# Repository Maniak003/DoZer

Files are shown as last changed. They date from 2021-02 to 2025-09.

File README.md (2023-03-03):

<!DOCTYPE html>
<html lang="en" data-color-mode="auto" data-light-theme="light" data-dark-theme="dark">
  <head>
    <meta charset="utf-8">
  </head>
    <body class="logged-in env-production page-responsive page-blob" style="word-wrap: break-word;">
      <a href="https://play.google.com/store/apps/details?id=ru.starline.dozer" rel="nofollow">Application download</a>
      <p> DoZer Scintillation gamma spectrometer based on SiPM Sensl FC60035/FJ60035, Broadcom AFBR-S4N66C013 & NaI(Tl) or SrI2(Eu).</p>
      <a href="https://github.com/Maniak003/DoZer/wiki/Description" rel="nofollow">
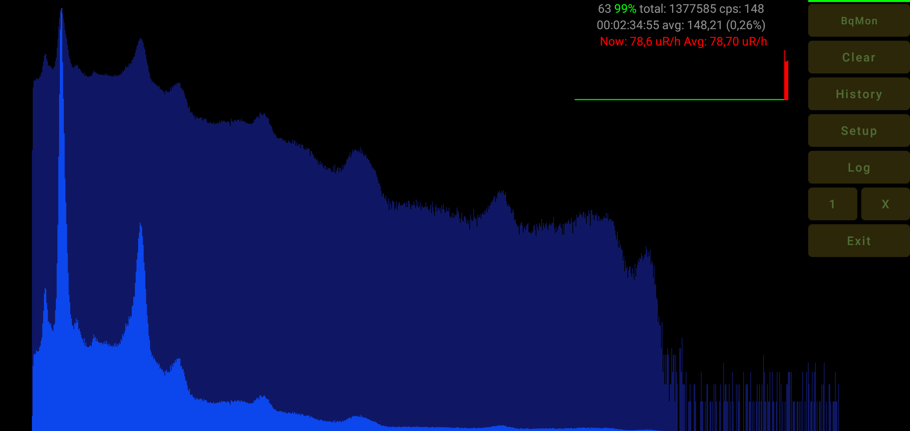
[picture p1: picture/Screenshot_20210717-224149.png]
Th-232
        
      </a>
      <a href="https://github.com/Maniak003/DoZer/wiki/Description" rel="nofollow">Description</a>
    </body>
</html>

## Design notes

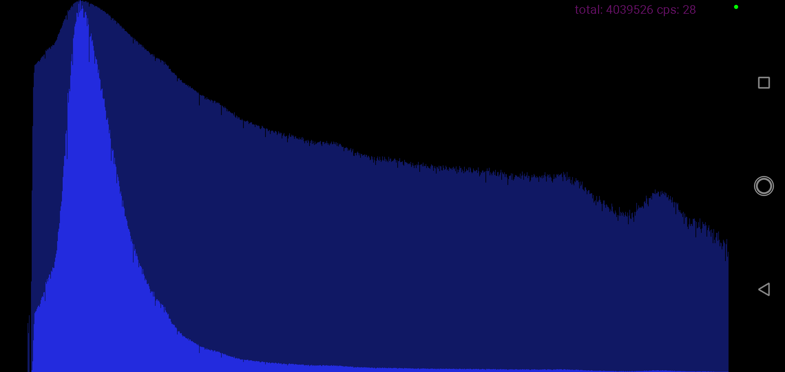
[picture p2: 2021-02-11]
picture/Screenshot_20210208-204545.png

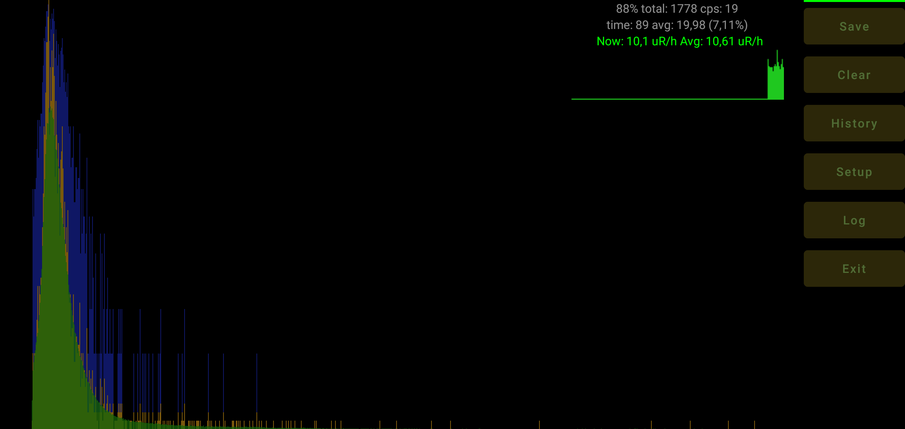
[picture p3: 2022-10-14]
picture/Screenshot_20210529-223236.png

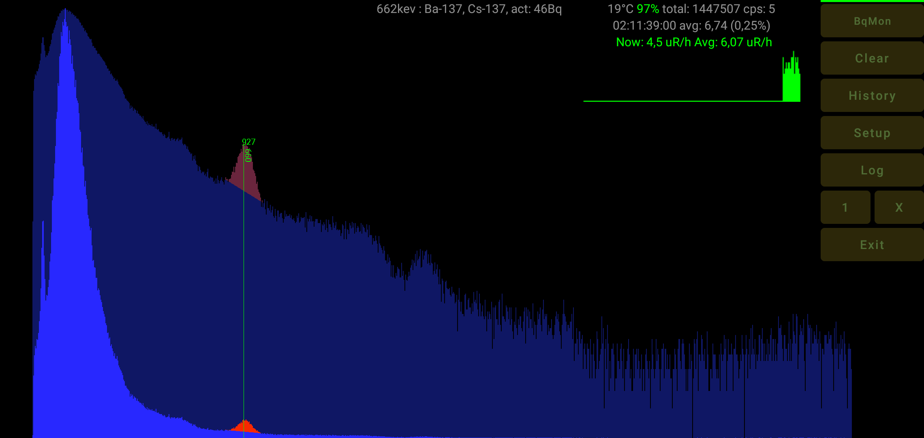
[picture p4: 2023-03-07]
picture/Screenshot_20230307-103208.png

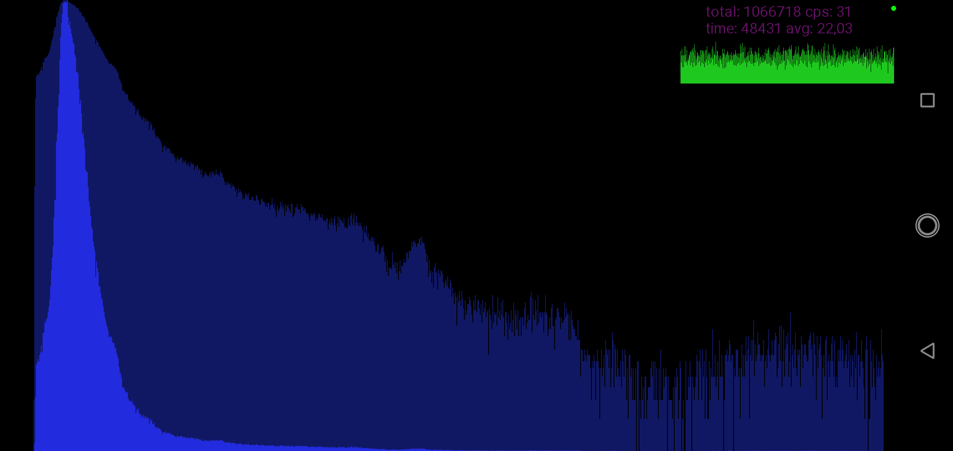
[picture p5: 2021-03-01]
picture/Screenshot_20210228-110633.png

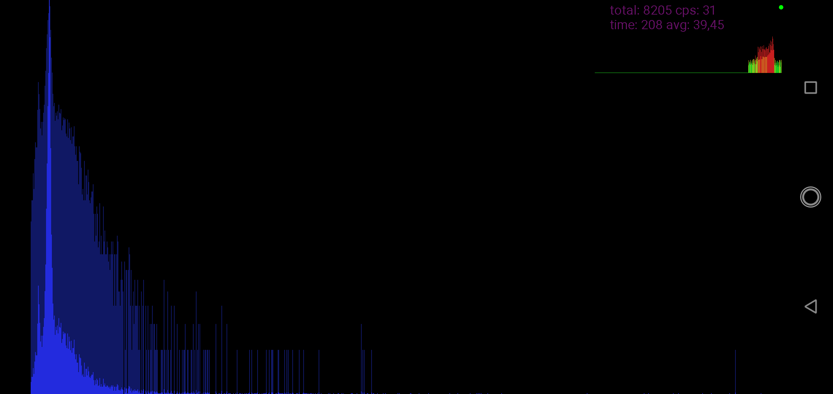
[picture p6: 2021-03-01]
picture/Screenshot_20210227-210718.png

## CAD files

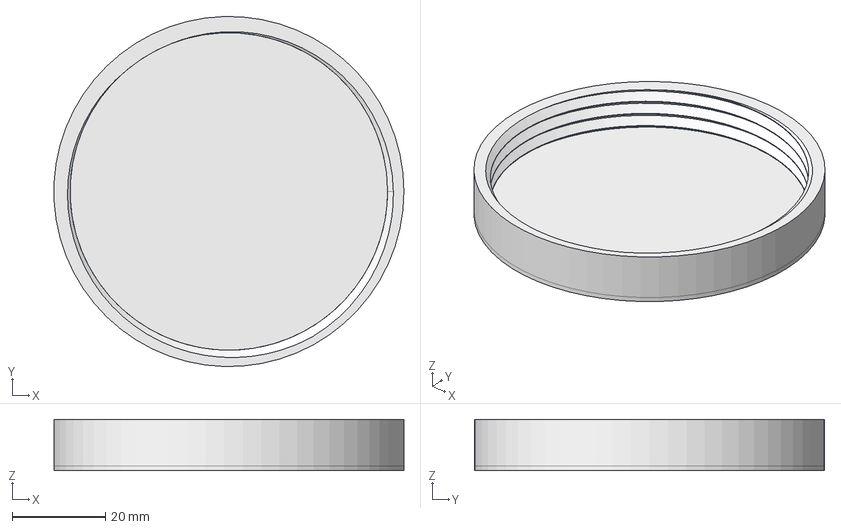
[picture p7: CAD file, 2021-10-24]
FreeCAD/Marinelly_cover.FCStd
74.9 x 75.0 x 11.0 mm

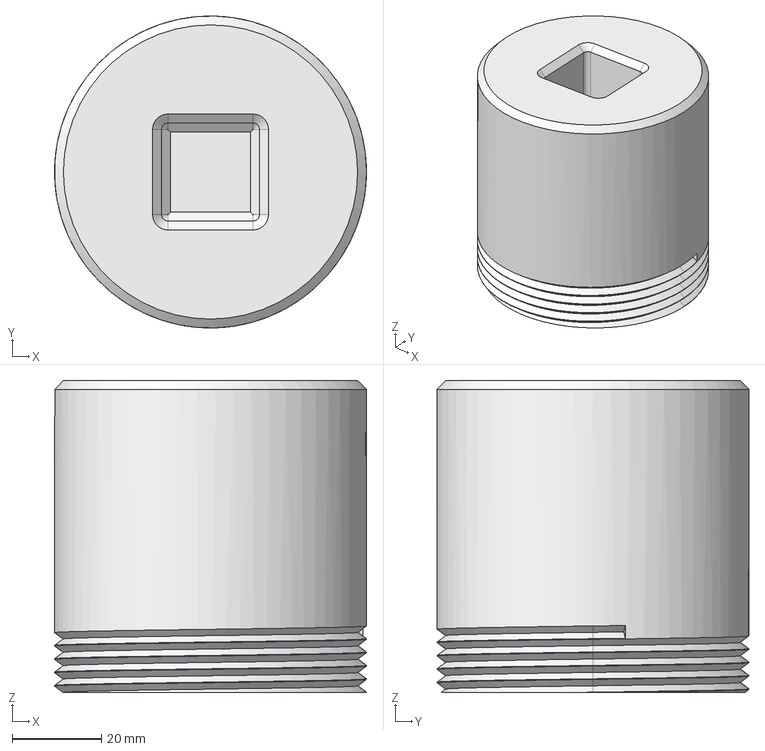
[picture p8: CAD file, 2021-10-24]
FreeCAD/Marinelly.FCStd
70.0 x 70.0 x 70.0 mm

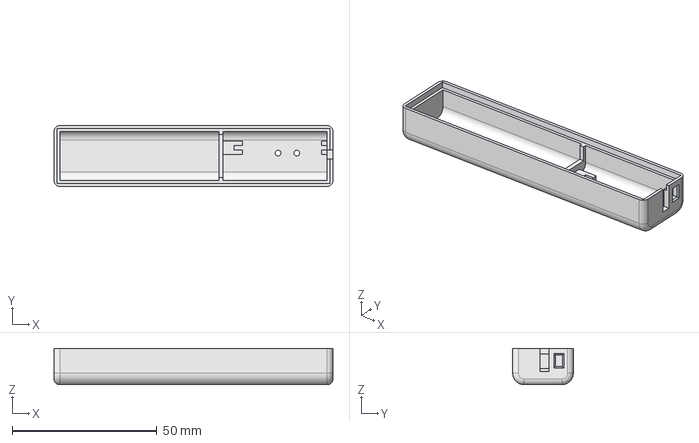
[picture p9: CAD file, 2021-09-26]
FreeCAD/sc-box-7.FCStd
96.5 x 21.0 x 12.6 mm

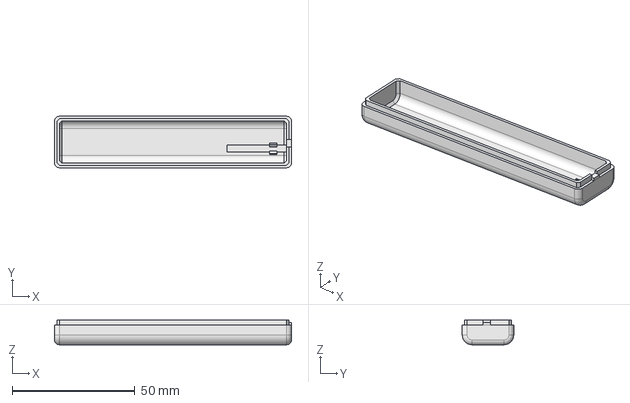
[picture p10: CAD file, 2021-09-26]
FreeCAD/sc-cover-7.FCStd
96.5 x 21.0 x 10.0 mm

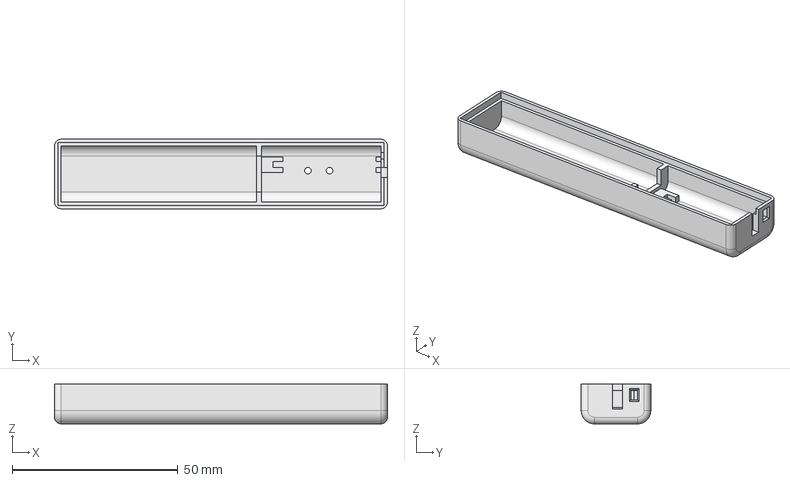
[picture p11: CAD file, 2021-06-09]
FreeCAD/sc-box-8.FCStd
100.5 x 21.0 x 12.0 mm

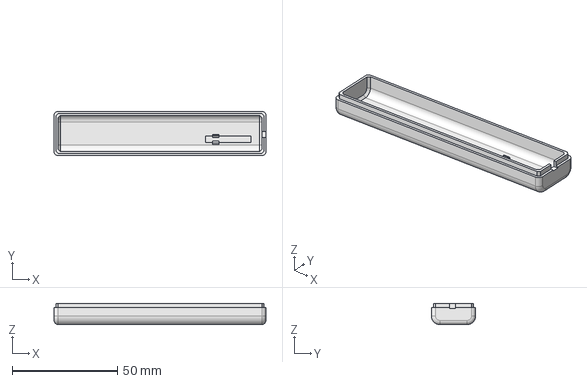
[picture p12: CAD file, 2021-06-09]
FreeCAD/sc-cover-8.FCStd
100.5 x 21.0 x 10.0 mm

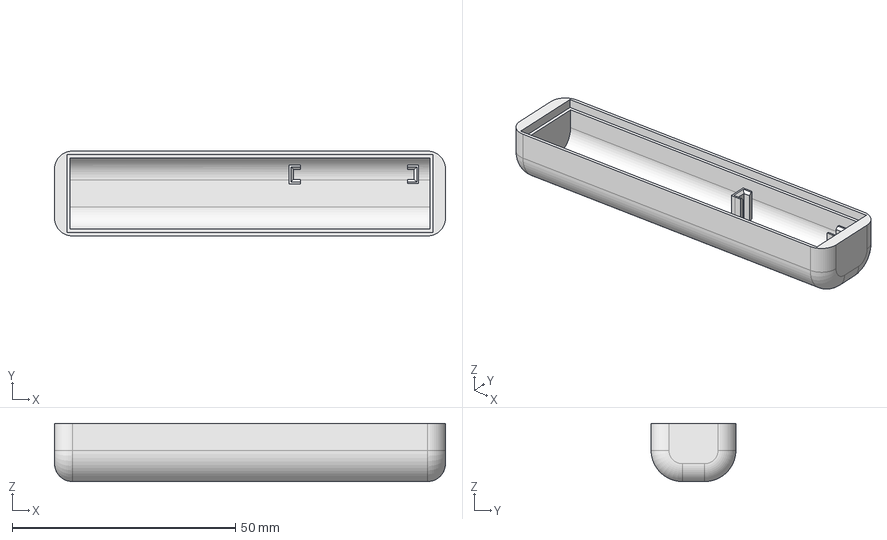
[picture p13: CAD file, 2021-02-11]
FreeCAD/sc-cover-5.FCStd
87.5 x 19.0 x 13.0 mm

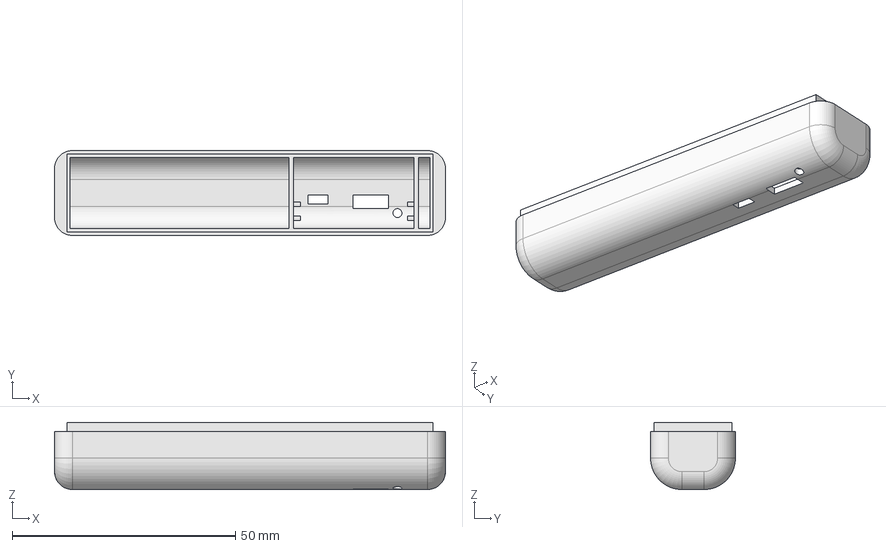
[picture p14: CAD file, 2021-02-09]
FreeCAD/sc-box-5.FCStd
87.5 x 19.0 x 15.0 mm

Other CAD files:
FreeCAD/Marinelly-cover.stl
FreeCAD/Marinelly.stl
FreeCAD/sc-box-5.stl
FreeCAD/sc-box-7.stl
FreeCAD/sc-cover-5.stl
FreeCAD/sc-cover-7.stl

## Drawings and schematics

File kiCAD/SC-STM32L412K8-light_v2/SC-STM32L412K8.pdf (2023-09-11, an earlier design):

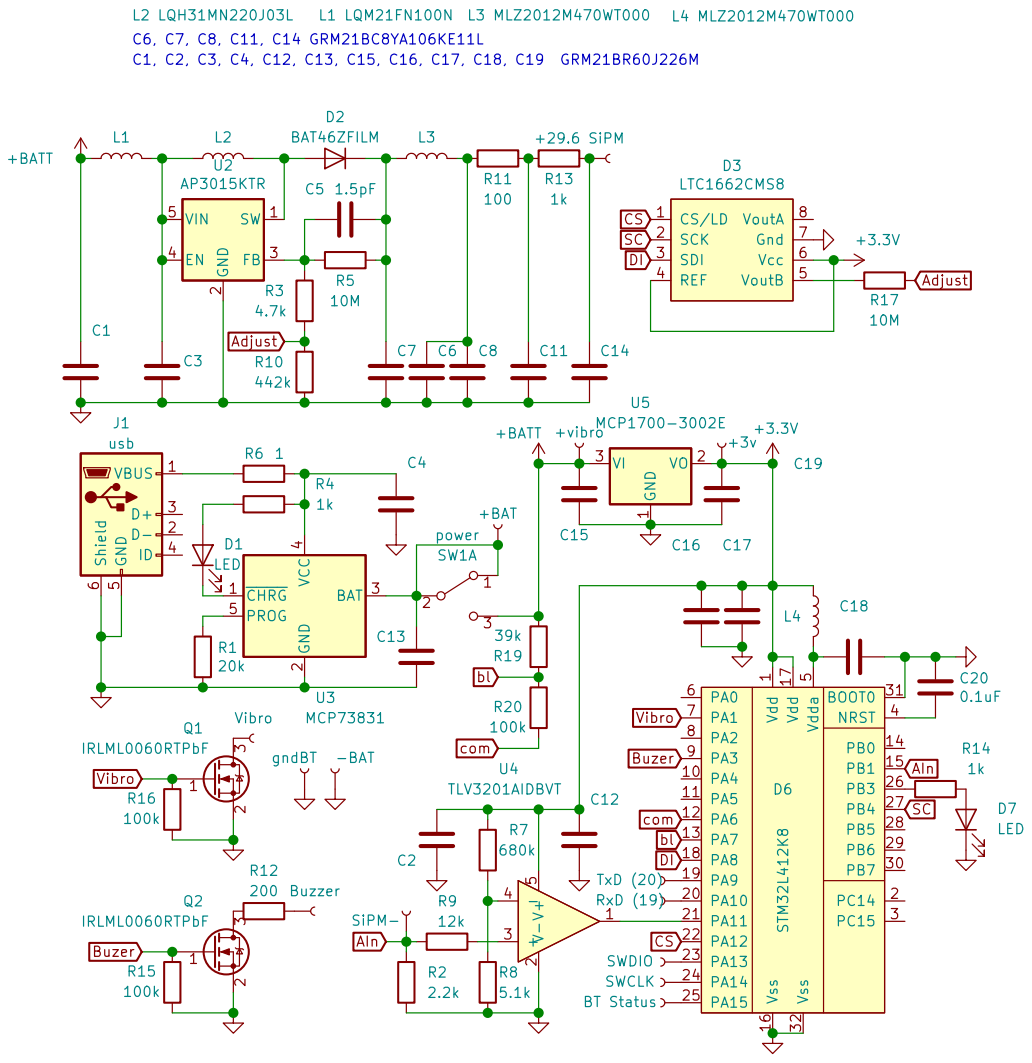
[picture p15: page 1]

1 PA4 10 PA5 11 PA6 12 PA7 13 PB0 14 PB1 15 Vss 16 Vdd 17 PA8 18 PA9 19 PC14 2 PA10 20 PA11 21 PA12 22 PA13 23 PA14 24 PA15 25 PB3 26 PB4 27 PB5 28 PB6 29 PC15 3 PB7 30 BOOT0 31 Vss 32 NRST 4 Vdda

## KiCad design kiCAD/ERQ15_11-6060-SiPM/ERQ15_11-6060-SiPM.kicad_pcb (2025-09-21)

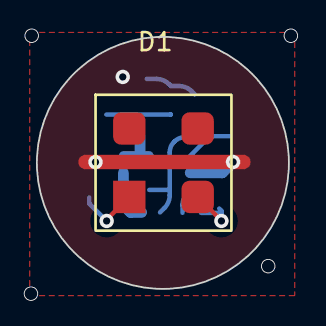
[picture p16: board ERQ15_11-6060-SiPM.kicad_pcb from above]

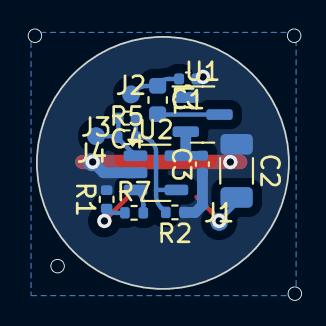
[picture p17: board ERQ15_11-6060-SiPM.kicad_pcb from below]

Board: 2 copper layers, 14.0 x 14.0 mm, 16 parts (15 on the bottom side), 9 nets.

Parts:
C1, C3: 10u; C_0402_1005Metric
C2: 10u; C_1206_3216Metric
C4: 2p; C_0402_1005Metric
D1: EQR15-11-6060D-S; EQR15_11-6060D-S
J1, J2, J3, J4: Conn; conn_mini
L1: 47uH; L_0603_1608Metric
R1: 1k; R_0402_1005Metric
R2, R7: 10k; R_0402_1005Metric
R5: 100k; R_0402_1005Metric
U1: MCP1700x-280xxTT; SOT-23
U2: OPA354; SOT-23-5

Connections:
+3V0: C3.2, U1.2 (VO), U2.5 (V+)
GND: C1.1, C2.1, C3.1, J4.1, R1.2, R2.1, U1.1 (GND), U2.2 (V-)
unnamed: C1.2, J2.1, L1.1
unnamed: C4.2, J3.1, R5.1, U2.1
unnamed: D1.2 (A), R1.1, R7.1
unnamed: C2.2, D1.1 (C), J1.1
unnamed: L1.2, U1.3 (VI)
unnamed: R7.2, U2.3 (+)
unnamed: C4.1, R2.2, R5.2, U2.4 (-)

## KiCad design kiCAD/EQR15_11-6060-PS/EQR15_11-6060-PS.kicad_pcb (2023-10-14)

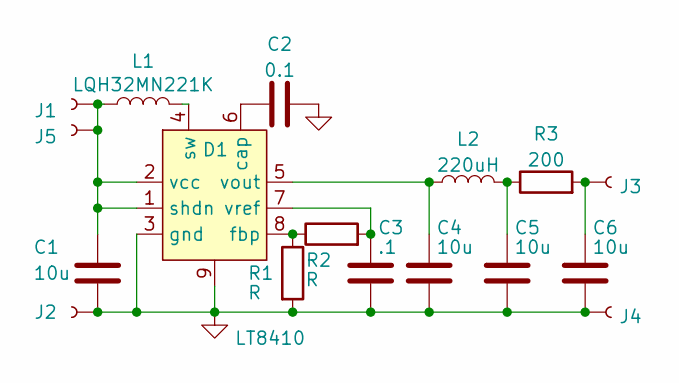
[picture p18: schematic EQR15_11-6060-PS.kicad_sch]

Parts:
C1: 10u; C_0402_1005Metric
C2: 0.1; C_0402_1005Metric
C3: .1; C_0402_1005Metric
C4, C5, C6: 10u; C_0805_2012Metric
D1: LT8410; DFN-8-1EP_2x2mm_P0.45mm_EP0.64x1.38mm
J1, J2, J3, J4, J5: Conn; conn_mini
L1: LQH32MN221K; L_1210_3225Metric
L2: 220uH; L_0805_2012Metric
R1, R2: R; R_0402_1005Metric
R3: 200; R_0402_1005Metric

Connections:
GND: C1.2, C2.2, C3.2, C4.2, C5.2, C6.2, D1.3 (gnd), D1.9, J2.1, J4.1, R1.2
unnamed: C1.1, D1.1 (shdn), D1.2 (vcc), J1.1, J5.1, L1.1
unnamed: C2.1, D1.6 (cap)
unnamed: C3.1, D1.7 (vref), R2.2
unnamed: C4.1, D1.5 (vout), L2.1
unnamed: C5.1, L2.2, R3.1
unnamed: C6.1, J3.1, R3.2
unnamed: D1.4 (sw), L1.2
unnamed: D1.8 (fbp), R1.1, R2.1

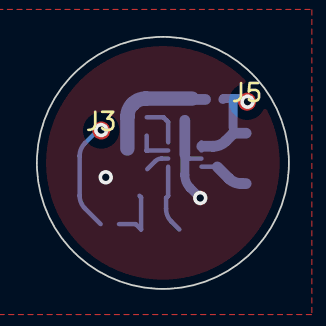
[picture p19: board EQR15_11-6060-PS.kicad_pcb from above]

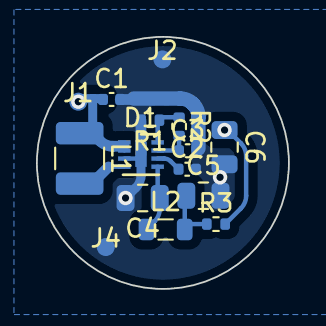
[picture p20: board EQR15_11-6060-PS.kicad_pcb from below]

Board: 2 copper layers, 14.0 x 14.0 mm, 17 parts (15 on the bottom side), 9 nets.

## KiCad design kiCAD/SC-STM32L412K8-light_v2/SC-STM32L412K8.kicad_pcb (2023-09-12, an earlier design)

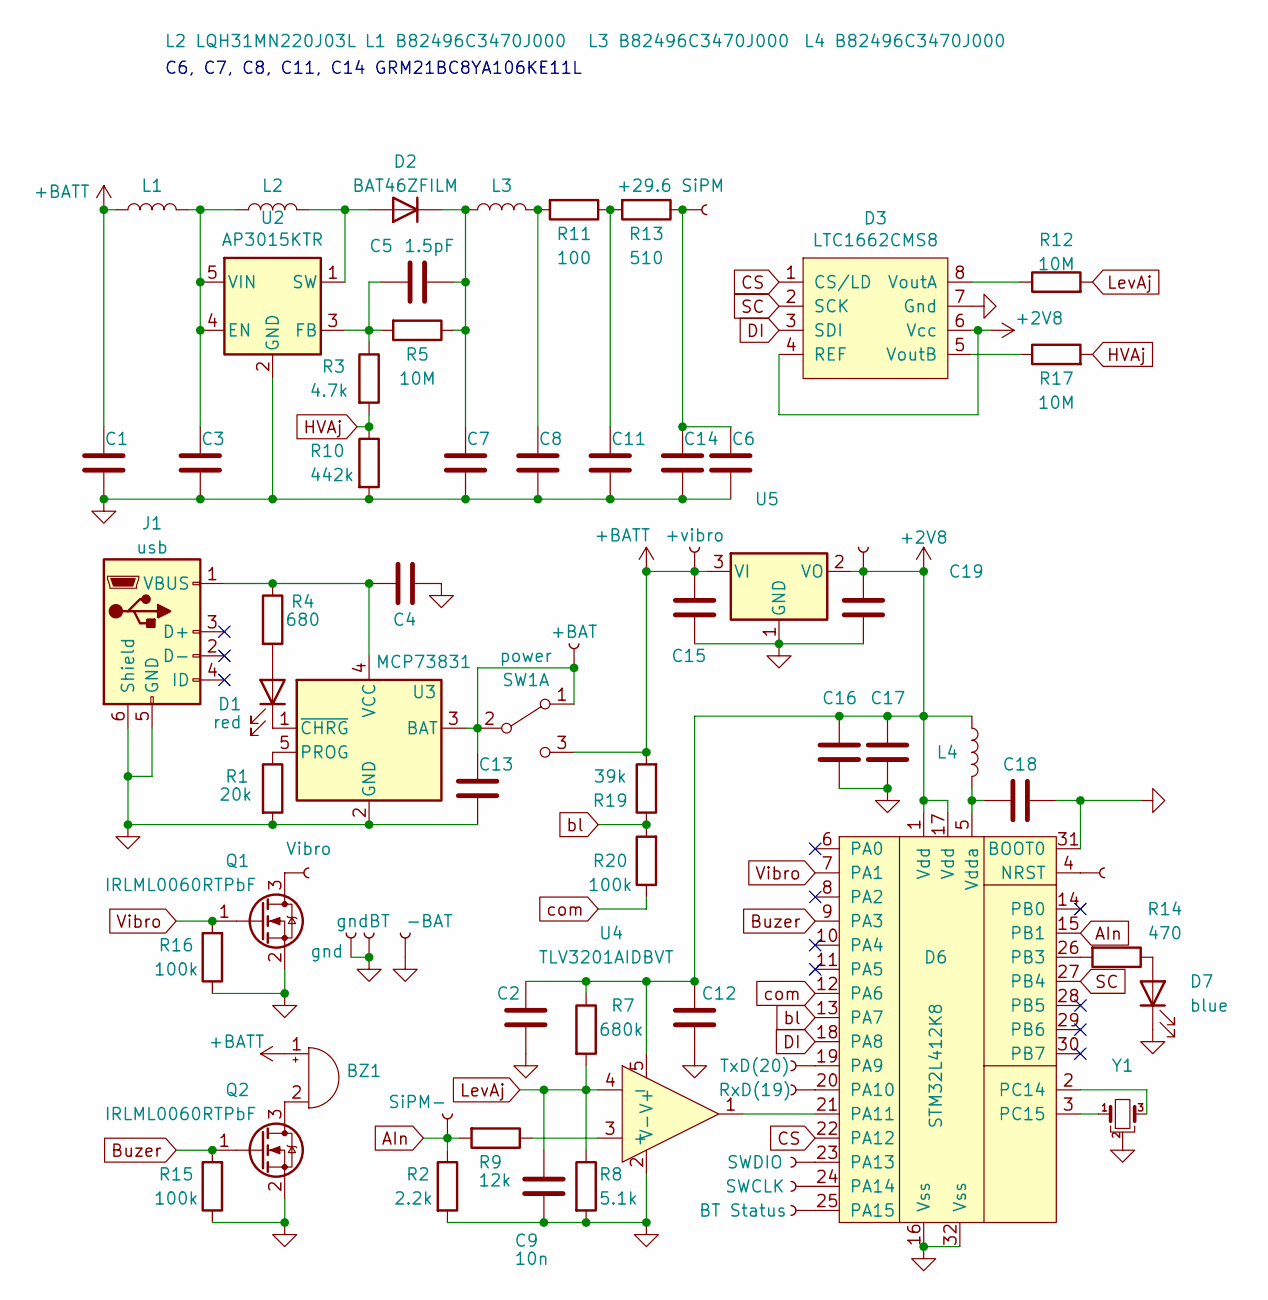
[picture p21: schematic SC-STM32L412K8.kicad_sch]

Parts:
BZ1: Buzzer; Buzzer5x5
C1, C2, C3, C4, C13, C15, C16, C17, C19: 1uF; C_0603_1608Metric
C5: 1.5pF; C_0603_1608Metric
C6, C7, C8, C11, C14: GRM21BC8YA106KE11L; C_0805_2012Metric
C9: 10n; C_0402_1005Metric
C12: GRM21BR60J226M; C_0805_2012Metric
C18: GRM21BR60J226M; C_0603_1608Metric
D1: red; LED_0402_1005Metric
D2: BAT46ZFILM; D_SOD-123
D3: LTC1662CMS8; MSOP-8_3x3mm_P0.65mm
D6: STM32L412K8; LQFP-32_7x7mm_P0.8mm
D7: blue; LED_0402_1005Metric
J1: usb; USB_Micro-B_Molex_47346-0001
J2: +29.6 SiPM; SMD-CONN
J3: TxD(20); conn_mini
J4: RxD(19); conn_mini
J5: SWDIO; conn_mini
J6: SWCLK; conn_mini
J7: +BAT; conn_mini
J8: SiPM-; SMD-CONN
J9: BT Status; conn_mini
J10: gnd; conn_mini
J11: Vibro; conn_mini
J12, J16: +2.8v; conn_mini
J13: +vibro; conn_mini
J14: gndBT; SMD-CONN
J15: -BAT; SMD-CONN
L1: L1 B82496C3470J000; L_0603_1608Metric
L2: L2 LQH31MN220J03L; L_1210_3225Metric
L3: L3 B82496C3470J000; L_0603_1608Metric
L4: L4 B82496C3470J000; L_0603_1608Metric
Q1, Q2: IRLML0060RTPbF; SOT-23
R1: 20k; R_0402_1005Metric
R2: 2.2k; R_0402_1005Metric
R3: 4.7k; R_0402_1005Metric
R4: 680; R_0402_1005Metric
R5: 10M; R_0603_1608Metric
R7: 680k; R_0402_1005Metric
R8: 5.1k; R_0402_1005Metric
R9: 12k; R_0402_1005Metric
R10: 442k; R_0402_1005Metric
R11: 100; R_0402_1005Metric
R12, R17: 10M; R_0402_1005Metric
R13: 510; R_0402_1005Metric
R14: 470; R_0402_1005Metric
R15, R16, R20: 100k; R_0402_1005Metric
R19: 39k; R_0603_1608Metric
SW1: power; MySwithc
U2: AP3015KTR; SOT-23-5
U3: MCP73831; TSOT-23-5
U4: TLV3201AIDBVT; SOT-23-5
U5: MCP1700-2802E; SOT-23
Y1: Crystal_GND2_Small; Resonator_SMD_Murata_CSTxExxV-3Pin_3.0x1.1mm

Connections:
+2V8: C2.1, C12.1, C16.1, C17.1, C19.1, D3.4 (REF), D3.6 (Vcc), D6.1 (Vdd), D6.17 (Vdd), J12.1, L4.1, R7.1, U4.5 (V+), U5.2 (VO)
+BATT: BZ1.1 (-), C1.2, C15.1, J13.1, L1.1, R19.2, SW1.3 (C), U5.3 (VI)
AIn: D6.15 (PB1), J8.1, R2.1, R9.2
Buzer: D6.9 (PA3), Q2.1 (G), R15.2
CS: D3.1 (CS/LD), D6.22 (PA12)
DI: D3.3 (SDI), D6.18 (PA8)
GND: C1.1, C2.2, C3.1, C4.1, C6.1, C7.1, C8.1, C9.2, C11.1, C12.2, C13.2, C14.1, C15.2, C16.2, C17.2, C18.1, C19.2, D3.7 (Gnd), D6.16 (Vss), D6.31 (BOOT0), D6.32 (Vss), D7.1 (K), J1.5 (GND), J1.6 (Shield), J10.1, J14.1, J15.1, Q1.2 (S), Q2.2 (S), R1.2, R2.2, R8.2, R10.2, R15.1, R16.1, U2.2 (GND), U3.2 (GND), U4.2 (V-), U5.1 (GND), Y1.2
HVAj: R3.2, R10.1, R17.2
LevAj: C9.1, R7.2, R8.1, R12.2, U4.4 (-)
unnamed: BZ1.2 (+), Q2.3 (D)
unnamed: C3.2, L1.2, L2.1, U2.4 (EN), U2.5 (VIN)
unnamed: C4.2, J1.1 (VBUS), R4.1, U3.4 (VCC)
unnamed: C5.1, C7.2, D2.1 (K), L3.1, R5.1
unnamed: C5.2, R3.1, R5.2, U2.3 (FB)
unnamed: C8.2, L3.2, R11.2
unnamed: C11.2, R11.1, R13.2
unnamed: C13.1, J7.1, SW1.1 (A), SW1.2 (B), U3.3 (BAT)
unnamed: C6.2, C14.2, J2.1, R13.1
unnamed: C18.2, D6.5 (Vdda), L4.2
unnamed: D1.1 (K), U3.1 (~CHRG)
unnamed: D1.2 (A), R4.2
unnamed: D2.2 (A), L2.2, U2.1 (SW)
unnamed: D3.5 (VoutB), R17.1
unnamed: D3.8 (VoutA), R12.1
unnamed: D6.2 (PC14), Y1.3
unnamed: D6.3 (PC15), Y1.1
unnamed: D6.4 (NRST), J16.1
unnamed: D6.19 (PA9), J3.1
unnamed: D6.20 (PA10), J4.1
unnamed: D6.21 (PA11), U4.1
unnamed: D6.23 (PA13), J5.1
unnamed: D6.24 (PA14), J6.1
unnamed: D6.25 (PA15), J9.1
unnamed: D6.26 (PB3), R14.2
unnamed: D7.2 (A), R14.1
unnamed: J11.1, Q1.3 (D)
unnamed: R1.1, U3.5 (PROG)
unnamed: R9.1, U4.3 (+)
SC: D3.2 (SCK), D6.27 (PB4)
Vibro: D6.7 (PA1), Q1.1 (G), R16.2
bl: D6.13 (PA7), R19.1, R20.2
com: D6.12 (PA6), R20.1

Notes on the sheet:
C6, C7, C8, C11, C14 GRM21BC8YA106KE11L

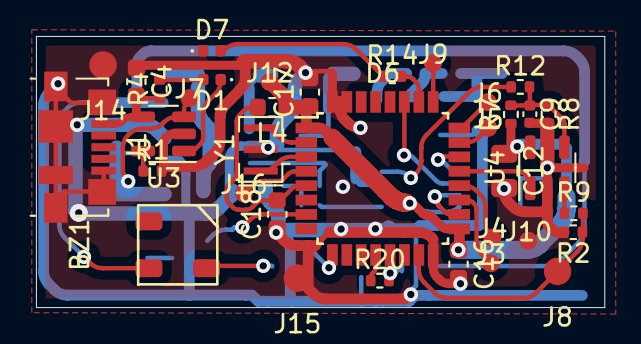
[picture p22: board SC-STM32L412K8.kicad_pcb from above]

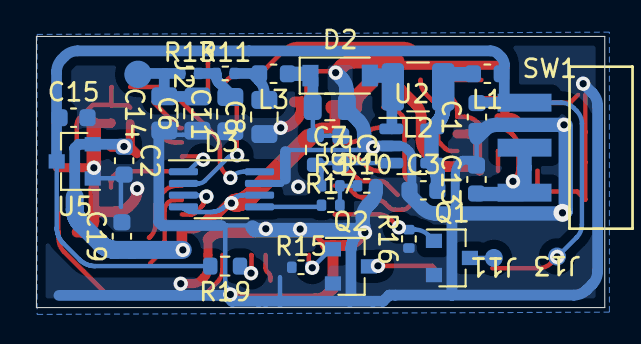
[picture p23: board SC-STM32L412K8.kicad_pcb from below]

Board: 2 copper layers, 31.6 x 15.1 mm, 70 parts (34 on the bottom side), 42 nets.

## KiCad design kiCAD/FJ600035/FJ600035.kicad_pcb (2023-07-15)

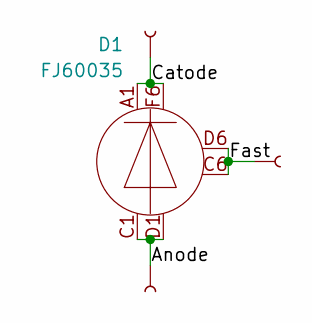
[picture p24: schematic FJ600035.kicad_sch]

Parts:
D1: FJ60035
J1, J2, J3: Conn; conn_mini

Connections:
/Anode: D1.C1, D1.D1, J2.1
/Catode: D1.A1, D1.F6, J1.1
/Fast: D1.C6, D1.D6, J3.1

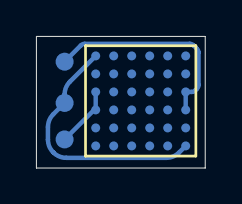
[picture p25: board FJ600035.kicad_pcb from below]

Board: 2 copper layers, 9.4 x 7.3 mm, 4 parts (4 on the bottom side), 3 nets.

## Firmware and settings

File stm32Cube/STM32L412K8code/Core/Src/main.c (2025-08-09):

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
/* Includes ------------------------------------------------------------------*/
#include "main.h"

/* USER CODE BEGIN Includes */
#ifdef DISPLAY_ENABLE
#include "ssd1306.h"
#include "ssd1306_fonts.h"
#endif
#include <stdio.h>

/* USER CODE END Includes */

ADC_HandleTypeDef hadc1;
ADC_HandleTypeDef hadc2;
DMA_HandleTypeDef hdma_adc1;

LPTIM_HandleTypeDef hlptim2;

TIM_HandleTypeDef htim2;
TIM_HandleTypeDef htim6;
TIM_HandleTypeDef htim15;
TIM_HandleTypeDef htim16;

UART_HandleTypeDef huart1;
DMA_HandleTypeDef hdma_usart1_rx;

/* USER CODE BEGIN PV */
char counterPP[20];
_Bool initFlag = 1, sleepFlag = 1, initUART = 1, logDataFlag = 0;
uint32_t counterCCAlarm = 0, counterCC = 0, counterALL = 0, sleepDelay, alarmTime = 0, oldInterval = 0, avgRadInterval, Thr1 = 0, Thr2 = 0, Thr3 = 0, batteryInterval;
uint16_t adc2Result = 0, adc1Result[2];
uint16_t spectrData[4096 + reservDataSize][2] = {0};
uint16_t spectrCRC, cfgData, cfgLevel1, cfgLevel2, cfgLevel3, powerCoeff, alarmLevel, alarmCount;
uint8_t indexBuffer;
uint32_t radBuffer[radBufferSize] = {0}, oldTimeAll;
uint8_t	resolution = 0, logIndex = 0, logRecords = 0, specterHistory = 0;
uint16_t dacValue, oldAlarmLevel = 4;
HAL_StatusTypeDef	flash_ok;

logData logDat[logSize];
float temperatureKoeff1, temperatureKoeff2;
//float cfgKoefRh;
static union {
	uint32_t uint;
	float flt;
}cfgKoef;

void bebe(void) {
	HAL_TIM_OC_Start(&htim2, TIM_CHANNEL_3); // Start timer for turn off Buzzer
	HAL_TIM_OC_Start(&htim2, TIM_CHANNEL_4); // Start timer for turn off Buzzer
	HAL_Delay(200);
	HAL_TIM_OC_Stop(&htim2, TIM_CHANNEL_3);
	HAL_TIM_OC_Stop(&htim2, TIM_CHANNEL_4);
	HAL_Delay(200);
	HAL_TIM_OC_Start(&htim2, TIM_CHANNEL_3); // Start timer for turn off Buzzer
	HAL_TIM_OC_Start(&htim2, TIM_CHANNEL_4); // Start timer for turn off Buzzer
	HAL_Delay(200);
	HAL_TIM_OC_Stop(&htim2, TIM_CHANNEL_3);
	HAL_TIM_OC_Stop(&htim2, TIM_CHANNEL_4);
}

/*
 * read/write config data from/to flash
 *
 * cfgData:
            00  -- Level 1 sound 1
            01  -- Level 1 vibro 2
            02  -- Level 2 sound 4
            03  -- Level 2 vibro 8
            04  -- Level 3 sound 16
            05  -- Level 3 vibro 32
            06  -- LED 64
            07  -- Sound 128
            08  -- 1 - 1024, 2 - 2048, 3 - 4096
            09  --
            10
            11
            12
            13
            14
            15
            16
 */
void rwFlash(uint8_t rwFlag) {
	uint32_t pageAdr = 0x800F800; // Begin of 31 page, last page flash for STM32L412K8.
	uint16_t magicKey;
	uint64_t dataForSave;
	magicKey = *(__IO uint16_t*) pageAdr;
	if ((magicKey != 0x1234) || (rwFlag == 1)) { // rwFlag == 1 for wrtite data to flash
		magicKey = 0x1234;
		if (rwFlag == 0) { // For first initial
			cfgData = 0;
			cfgLevel1 = 0;
			cfgLevel2 = 0;
			cfgLevel3 = 0;
			powerCoeff = 256;
		}
		FLASH_EraseInitTypeDef EraseInitStruct;
		uint32_t PAGEError = 0;
		EraseInitStruct.TypeErase   = FLASH_TYPEERASE_PAGES;
		EraseInitStruct.Page = 31; // Page size for STM32L412K8 is 2KB
		EraseInitStruct.NbPages     = 1;

		flash_ok = HAL_ERROR;
		// Unlock flash
		while(flash_ok != HAL_OK) {
		  flash_ok = HAL_FLASH_Unlock();
		}
		if (HAL_FLASHEx_Erase(&EraseInitStruct, &PAGEError) == HAL_OK) {

			dataForSave = (uint64_t) (magicKey | (((uint32_t) powerCoeff << 16) & 0xFFFF0000 ) | (((uint64_t) cfgData << 32) & 0xFFFFFFFF00000000) | (((uint64_t) cfgLevel1 << 48) & 0xFFFF000000000000));
			flash_ok = HAL_ERROR;
			while(flash_ok != HAL_OK){
				flash_ok = HAL_FLASH_Program(FLASH_TYPEPROGRAM_DOUBLEWORD, pageAdr, dataForSave); // Write  magic key into Flash
			}

			dataForSave = (uint64_t) (cfgLevel2 | (cfgLevel3 << 16) | (uint64_t) cfgKoef.uint << 32);
			flash_ok = HAL_ERROR;
			while(flash_ok != HAL_OK) {
				flash_ok = HAL_FLASH_Program(FLASH_TYPEPROGRAM_DOUBLEWORD, pageAdr + 8, dataForSave); // Write Level2, Level3
			}
		}
		// Lock flash
		flash_ok = HAL_ERROR;
		while(flash_ok != HAL_OK) {
			flash_ok = HAL_FLASH_Lock();
		}
		bebe();
	} else {
		powerCoeff = *(__IO uint16_t*) (pageAdr + 2);
		cfgData = *(__IO uint16_t*) (pageAdr + 4);
		resolution = (uint8_t) (cfgData >> 8 & 0x3);
		cfgLevel1 = *(__IO uint16_t*) (pageAdr + 6);
		cfgLevel2 = *(__IO uint16_t*) (pageAdr + 8);
		cfgLevel3 = *(__IO uint16_t*) (pageAdr + 10);
		uint32_t koefAddr = pageAdr + 12;
		cfgKoef.uint = *(__IO uint32_t*) (koefAddr);
		if (cfgKoef.flt > 0) {
			float tmpVal = cfgKoef.flt * 1000;
			Thr1 = (uint32_t) (tmpVal / (float)cfgLevel1);
			Thr2 = (uint32_t) (tmpVal / (float)cfgLevel2);
			Thr3 = (uint32_t) (tmpVal / (float)cfgLevel3);
		}
	}
}

/* USER CODE END PV */

void SystemClock_Config(void);
static void MX_GPIO_Init(void);
static void MX_DMA_Init(void);
static void MX_ADC1_Init(void);
static void MX_USART1_UART_Init(void);
static void MX_TIM15_Init(void);
static void MX_ADC2_Init(void);
static void MX_TIM2_Init(void);
static void MX_TIM16_Init(void);
static void MX_TIM6_Init(void);
static void MX_LPTIM2_Init(void);
/**
  * @brief  The application entry point.
  * @retval int
  */
int main(void)
{
  /* MCU Configuration--------------------------------------------------------*/

  /* Reset of all peripherals, Initializes the Flash interface and the Systick. */
  HAL_Init();

  /* Configure the system clock */
  SystemClock_Config();

  /* Initialize all configured peripherals */
  MX_GPIO_Init();
  MX_DMA_Init();
  MX_ADC1_Init();
  MX_USART1_UART_Init();
  MX_TIM15_Init();
  MX_ADC2_Init();
  MX_TIM2_Init();
  MX_TIM16_Init();
  MX_TIM6_Init();
  MX_LPTIM2_Init();
  /* USER CODE BEGIN 2 */
  HAL_LPTIM_Counter_Stop_IT(&hlptim2);
  //HAL_PWREx_EnableLowPowerRunMode();
  /* USER CODE END 2 */

  /* Infinite loop */
  /* USER CODE BEGIN WHILE */
  int j = 0;
  uint8_t btCommand[sizeCommand];
  uint8_t prefix[3] = {'<', 'B', '>'};
  uint8_t lowSpectr, highSpectr;
  #ifdef DISPLAY_ENABLE
  ssd1306_Init();
  #endif
  //uint16_t tmpData;
  /*
   * Температура с учетом калибровки
   * (TS_CAL2_TEMP - TS_CAL1_TEMP) / (TS_CAL2 - TS_CAL1) * (TS_DATA - TS_CAL1) + 30
   *
   * */
  temperatureKoeff1 = (float) (TEMPSENSOR_CAL2_TEMP - TEMPSENSOR_CAL1_TEMP) / (float) (*TEMPSENSOR_CAL2_ADDR - *TEMPSENSOR_CAL1_ADDR);
  temperatureKoeff2 = 30 - temperatureKoeff1 * (float) ( *(__IO uint16_t*) TEMPSENSOR_CAL1_ADDR);
  temperatureKoeff1 = temperatureKoeff1 * 4 * ADC_REF_VOLTAGE / 3.0f;	// ADC 10 разрядов, default Vref = 3v.

  uint32_t initDelay, oldTime = HAL_GetTick();
  initDelay = oldTime;
  oldTimeAll = oldTime;
  sleepFlag = oldTime;
  batteryInterval = 0;
  counterCC = 0;

  rwFlash(0); // Read config from flash.

  if (powerCoeff == 0 || powerCoeff > 4095) {
	  powerCoeff = 60;
  }
  HAL_GPIO_WritePin(GPIOB, LED_PIN, GPIO_PIN_SET); // LED on.
  HAL_GPIO_WritePin(GPIOA, COM_PIN, GPIO_PIN_SET); // Com pin disable
  __HAL_TIM_CLEAR_FLAG(&htim15, TIM_SR_UIF); // Clear flags
  HAL_TIM_Base_Start_IT(&htim15); // Start timer for turn off LED
  //
  HAL_TIM_OC_Start(&htim2, TIM_CHANNEL_3);  // Sound on
  HAL_TIM_OC_Start(&htim2, TIM_CHANNEL_4);  // Sound on
  HAL_GPIO_WritePin(GPIOA, VIBRO_PIN, GPIO_PIN_SET); // Vibro on.
  __HAL_TIM_CLEAR_FLAG(&htim16, TIM_SR_UIF); // Clear flags
  HAL_TIM_Base_Start_IT(&htim16); // Start timer for turn off Buzzer

  alarmLevel = 0;
  alarmCount = 0;
  HAL_TIM_Base_Start_IT(&htim6); // Alarm timer.
  //HAL_UART_Init(&huart1);

  while (1)
  {
	#ifdef DISPLAY_ENABLE
	  sprintf(counterPP, "CPS:%lu CNT:%lu", counterCC / ((HAL_GetTick() - oldTime) / 1000), counterALL);
	  counterCC = 0;
	  oldTime = HAL_GetTick();
	  ssd1306_SetCursor(0, 0);
	  ssd1306_WriteString(counterPP, Font_6x8, 0x01);
	#endif
	  uint32_t max = 1;
	  for ( int i = reservDataSize; i < 2050; i++) {
		  if (spectrData[i][0] > max)
			  max = spectrData[i][0];
	  }
	#ifdef DISPLAY_ENABLE
	  sprintf(counterPP, "AVG:%lu MAX:%d", counterALL / ((HAL_GetTick() - oldTimeAll) / 1000), max);
	  ssd1306_SetCursor(0, 8);
	  ssd1306_WriteString(counterPP, Font_6x8, 0x01);

	  sprintf(counterPP, "TM:%lu",(HAL_GetTick() - oldTimeAll) / 1000);
	  ssd1306_SetCursor(0, 16);
	  ssd1306_WriteString(counterPP, Font_6x8, 0x01);
	#endif
	/*
	  //
	  // Histogram for LCD 64x128.
	  //
	  int k = 0;
	  for ( int i = 0; i < 119; i++) {
		  sptDat =(float) ((spectrData[k++] + spectrData[k++] + spectrData[k++]) * 64 / max);
		  //sptDat = (float) (log2f((float) spectrData[i]) * 64 / max);
		  ssd1306_Line(0, i + 9, 64, i + 9, 0x00);
		  ssd1306_Line(0, i + 9, sptDat, i + 9, 0x01);
	  }
	  */
	#ifdef DISPLAY_ENABLE
	  ssd1306_UpdateScreen();
	#endif
	  // Delay after on.
	  if (initFlag && (HAL_GetTick() - initDelay > INIT_TIME)) {
		  initFlag = 0;
		  HAL_ADC_Start_IT(&hadc2);  // Init ADC for sipm channel.
		  oldTimeAll = HAL_GetTick();
		  HAL_LPTIM_Counter_Start_IT(&hlptim2, 32000);
	  }
	#ifdef DISPLAY_ENABLE
	  ssd1306_SetCursor(0, 24);
	#endif
	  /* Status JDY-19, BT connected ? */
	  if ( HAL_GPIO_ReadPin(GPIOA, GPIO_PIN_15) == 1 ) { // BT State active ?
	#ifdef DISPLAY_ENABLE
		  ssd1306_WriteString("BT: connect   ", Font_6x8, 0x01);
	#endif
		  /* Init uart after sleep */
		  if (initUART) {
			  HAL_UART_Init(&huart1);
			  HAL_UART_Receive_DMA(&huart1, btCommand, sizeCommand);
			  initUART = 0;
		  }

		  /* Receive data from android */
		  if (hdma_usart1_rx.State == HAL_DMA_STATE_READY) {
			  HAL_UART_Receive_DMA(&huart1, btCommand, sizeCommand);
			  if (btCommand[0] == '<' && btCommand[2] == '>') {
				  uint16_t CS = 0;
				  for (int i = 0; i < 18; i++) {
					  CS = CS + btCommand[i];
				  }
				  if (((CS & 0xFF) == btCommand[18]) && (((CS >> 8) & 0xFF) == btCommand[19])) {
					  //HAL_TIM_OC_Start(&htim2, TIM_CHANNEL_4);
					  //HAL_TIM_Base_Start_IT(&htim16); // Start timer for turn off Buzzer
					  if (btCommand[1] == '1')  { // Clear statistics
						  for (int i = 0; i < 2050; i++) {
							  spectrData[i][specterHistory] = 0;
							  batteryInterval = 0;
							  if (specterHistory == 1) {
								  counterCCAlarm = 0;
								  alarmTime = 0;
							  }
						  }
						  oldTimeAll = HAL_GetTick();
						  counterALL = 0;
					  } else if (btCommand[1] == '2') { // Write config data
						  cfgData = ((btCommand[4] << 8) & 0xFF00) | btCommand[3];
						  resolution = (uint8_t) (cfgData >> 8 & 0x3);
						  cfgLevel1 = ((btCommand[6] << 8) & 0xFF00) | btCommand[5];
						  cfgLevel2 = ((btCommand[8] << 8) & 0xFF00) | btCommand[7];
						  cfgLevel3 = ((btCommand[10] << 8) & 0xFF00) | btCommand[9];
						  //cfgKoefRh = *(float *) &btCommand[11];
						  cfgKoef.uint = (uint32_t) (btCommand[11] | (uint32_t) btCommand[12] << 8 | (uint32_t) btCommand[13] << 16 | (uint32_t) btCommand[14] << 24);
						  powerCoeff = (uint16_t) (btCommand[15] | (uint16_t) btCommand[16] << 8);
						  if (cfgKoef.flt > 0) {
							  //float tmpVal = cfgKoefRh * 1000;
							  float tmpVal = cfgKoef.flt * 1000;
							  Thr1 = (uint32_t) (tmpVal / (float)cfgLevel1);
							  Thr2 = (uint32_t) (tmpVal / (float)cfgLevel2);
							  Thr3 = (uint32_t) (tmpVal / (float)cfgLevel3);
						  }
						  rwFlash(1); // Write to flash
					  } else if (btCommand[1] == '3') {  // Request log data.
						  logDataFlag = 1;
					  } else if (btCommand[1] == '4') {  // Toggle to alarm specter array
						  specterHistory = 1;
					  } else if (btCommand[1] == '5') {  // Toggle to normal specter array
						  specterHistory = 0;
					  }
				  }
			  }
		  }

		  /*
		   *  Transmit data over BT.
		   */
		  if (logDataFlag == 0) {  // Specter data
			  if (specterHistory == 0) {
				  prefix[1] = 'B';		// Normal specter
				  spectrData[0][specterHistory] = (uint16_t) ((HAL_GetTick() - oldTimeAll) / 1000); // Specter collection time.
				  spectrData[1][specterHistory] = (uint16_t) (((HAL_GetTick() - oldTimeAll) / 1000) >> 16);
				  spectrData[2][specterHistory] = (uint16_t) (counterALL & 0xFFFF);
				  spectrData[3][specterHistory] = (uint16_t) (counterALL >> 16);
			  } else {
				  prefix[1] = 'b';		// Alarm specter
				  spectrData[0][specterHistory] = (uint16_t) (alarmTime & 0xFFFF); // Specter collection time.
				  spectrData[1][specterHistory] = (uint16_t) (alarmTime >> 16);
				  spectrData[2][specterHistory] = (uint16_t) (counterCCAlarm & 0xFFFF);
				  spectrData[3][specterHistory] = (uint16_t) (counterCCAlarm >> 16);
			  }
			  HAL_UART_Transmit(&huart1, prefix, 3, 1000); // Start sequence.
			  //spectrData[2] = 0;
			  //spectrData[3] = 1;
			  spectrCRC = 0;
			  HAL_Delay(TRANSMIT_DALAY);  // Increase time delay if transmit error.
			  j = 0;
			  for ( int i = 0; i < 1042; i++) {
				  lowSpectr = spectrData[i][specterHistory] & 0xFF;
				  highSpectr = (spectrData[i][specterHistory] & 0xFF00) >> 8;
				  spectrCRC = spectrCRC + lowSpectr + highSpectr;
				  HAL_UART_Transmit(&huart1, &highSpectr, 1, 1000);
				  HAL_UART_Transmit(&huart1, &lowSpectr, 1, 1000);
				  if ( j++ >= 9) {
					  HAL_Delay(TRANSMIT_DALAY);  // Increase time delay if transmit error.
					  j = 0;
				  }
			  }
		  } else {  // Log data
			  uint32_t logTime = HAL_GetTick() / 1000;
			  uint8_t emptyBuff[5] = {0};
			  logDataFlag = 0;	// Reset log data flag
			  prefix[1] = 'L';
			  HAL_UART_Transmit(&huart1, prefix, 3, 1000); // Start sequence.
			  HAL_UART_Transmit(&huart1, &logRecords, 1, 1000); // Records count
			  spectrCRC = logRecords;
			  /* Send current time */
			  lowSpectr = logTime & 0xFF;
			  highSpectr = (logTime & 0xFF00) >> 8;
			  spectrCRC = spectrCRC + lowSpectr + highSpectr;
			  HAL_UART_Transmit(&huart1, &highSpectr, 1, 1000);
			  HAL_UART_Transmit(&huart1, &lowSpectr, 1, 1000);
			  lowSpectr = (logTime & 0xFF0000) >> 16;
			  highSpectr = (logTime & 0xFF000000) >> 24;
			  spectrCRC = spectrCRC + lowSpectr + highSpectr;
			  HAL_UART_Transmit(&huart1, &highSpectr, 1, 1000);
			  HAL_UART_Transmit(&huart1, &lowSpectr, 1, 1000);
			  HAL_UART_Transmit(&huart1, emptyBuff, 5, 1000);
			  HAL_Delay(TRANSMIT_DALAY);  // Increase time delay if transmit error.
			  j = 0;
			  for (int i = 0; i < logRecords; i++) {
				  lowSpectr = logDat[i].timeData & 0xFF;
				  highSpectr = (logDat[i].timeData & 0xFF00) >> 8;
				  spectrCRC = spectrCRC + lowSpectr + highSpectr;
				  HAL_UART_Transmit(&huart1, &highSpectr, 1, 1000);
				  HAL_UART_Transmit(&huart1, &lowSpectr, 1, 1000);
				  lowSpectr = (logDat[i].timeData & 0xFF0000) >> 16;
				  highSpectr = (logDat[i].timeData & 0xFF000000) >> 24;
				  spectrCRC = spectrCRC + lowSpectr + highSpectr;
				  HAL_UART_Transmit(&huart1, &highSpectr, 1, 1000);
				  HAL_UART_Transmit(&huart1, &lowSpectr, 1, 1000);
				  spectrCRC = spectrCRC + logDat[i].eventType;
				  HAL_UART_Transmit(&huart1, &logDat[i].eventType, 1, 1000);
				  lowSpectr = logDat[i].event_data & 0xFF;
				  highSpectr = (logDat[i].event_data & 0xFF00) >> 8;
				  spectrCRC = spectrCRC + lowSpectr + highSpectr;
				  HAL_UART_Transmit(&huart1, &highSpectr, 1, 1000);
				  HAL_UART_Transmit(&huart1, &lowSpectr, 1, 1000);
				  lowSpectr = (logDat[i].event_data & 0xFF0000) >> 16;
				  highSpectr = (logDat[i].event_data & 0xFF000000) >> 24;
				  spectrCRC = spectrCRC + lowSpectr + highSpectr;
				  HAL_UART_Transmit(&huart1, &highSpectr, 1, 1000);
				  HAL_UART_Transmit(&huart1, &lowSpectr, 1, 1000);
				  HAL_Delay(TRANSMIT_DALAY);  // Increase time delay if transmit error.
			  }
		  }
		  /* Transmit CRC */
		  HAL_Delay(TRANSMIT_DALAY);
		  lowSpectr = spectrCRC & 0xFF;
		  highSpectr = (spectrCRC & 0xFF00) >> 8;
		  HAL_UART_Transmit(&huart1, &highSpectr, 1, 1000);
		  HAL_UART_Transmit(&huart1, &lowSpectr, 1, 1000);
		  sleepDelay = HAL_GetTick();
		  sleepFlag = 1;
	  } else {
	#ifdef DISPLAY_ENABLE
		  HAL_Delay(500);
		  ssd1306_WriteString("BT: disconnect", Font_6x8, 0x01);
	#endif
		  // BT sleep control
		  if (sleepFlag && (HAL_GetTick() - sleepDelay > SLEEPDALAY)) {
			  sleepFlag = 0;
			  HAL_UART_Transmit(&huart1, (uint8_t*) "AT+SLEEP\n", 9, 1000);    //For JDY-10
			  HAL_Delay(200);
			  HAL_UART_Transmit(&huart1, (uint8_t*) "AT+SLEEP\r\n", 10, 1000); //For JDY-19
			  HAL_GPIO_WritePin(GPIOB, LED_PIN, GPIO_PIN_SET); // LED on.
			  HAL_TIM_Base_Start_IT(&htim15); // Start timer for turn off LED.
			  HAL_UART_DeInit(&huart1);
			  initUART = 1;
		  }
	  }
	  /*
	   * Measure battery voltage and temperature
	   */
	  if ((HAL_GetTick() - batteryInterval > batteryMeasureInterval) || batteryInterval == 0) {
		  HAL_GPIO_WritePin(GPIOA, COM_PIN, GPIO_PIN_RESET); // Enable common pin
		  HAL_ADC_Start_DMA(&hadc1, (uint32_t *) &adc1Result, 2);
		  batteryInterval = HAL_GetTick();

		  /*
		   * DAC LTC1662 control
		   * Less value, more voltage.
		   */
		  if (dacValue != powerCoeff) {
			  dacValue = powerCoeff;  // Constant for test
			  uint16_t transmitData = 0xA000 | dacValue;
			  HAL_GPIO_WritePin(GPIOA, CS_DAC, GPIO_PIN_SET);		// Disable CS pin
			  HAL_GPIO_WritePin(GPIOB, SCK_DAC, GPIO_PIN_SET);		// Pulse on SCK pin
			  HAL_GPIO_WritePin(GPIOB, SCK_DAC, GPIO_PIN_RESET);
			  HAL_GPIO_WritePin(GPIOA, CS_DAC, GPIO_PIN_RESET);		// Enable CS pin
			  for (int i = 0; i < 16; i++) {
				  if ((transmitData & (1 << (15 - i))) == 0) {
					  HAL_GPIO_WritePin(GPIOA, SDI_DAC, GPIO_PIN_RESET);
				  } else {
					  HAL_GPIO_WritePin(GPIOA, SDI_DAC, GPIO_PIN_SET);
				  }
				  HAL_GPIO_WritePin(GPIOB, SCK_DAC, GPIO_PIN_SET);		// Pulse on SCK pin
				  HAL_GPIO_WritePin(GPIOB, SCK_DAC, GPIO_PIN_RESET);
			  }
			  HAL_GPIO_WritePin(GPIOA, CS_DAC, GPIO_PIN_SET);		// Disable CS pin and execute command
		  }
	  }
	  HAL_Delay(500);
    /* USER CODE END WHILE */

    /* USER CODE BEGIN 3 */
  }
  /* USER CODE END 3 */
}

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


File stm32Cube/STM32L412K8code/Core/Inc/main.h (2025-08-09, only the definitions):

#define INIT_TIME  2000
#define TRANSMIT_DALAY 20
#define SLEEPDALAY 1000
#define VIBRO_PIN GPIO_PIN_1
#define LED_PIN GPIO_PIN_3
#define COM_PIN GPIO_PIN_6
#define SCK_DAC GPIO_PIN_4
#define SDI_DAC GPIO_PIN_8
#define CS_DAC GPIO_PIN_12
#define BUZZER GPIO_PIN_3
#define sizeCommand 20
#define radBufferSize 50
#define reservDataSize 6
#define batteryMeasureInterval 20000
#define logSize 200
#define ADC_REF_VOLTAGE 1.8f
#define Vibro_Pin GPIO_PIN_1
#define Vibro_GPIO_Port GPIOA
#define Buzzer_Pin GPIO_PIN_3
#define Buzzer_GPIO_Port GPIOA
#define COM_Pin GPIO_PIN_6
#define COM_GPIO_Port GPIOA
#define BAT_LEVEL_Pin GPIO_PIN_7
#define BAT_LEVEL_GPIO_Port GPIOA
#define SiPM_Pin GPIO_PIN_1
#define SiPM_GPIO_Port GPIOB
#define BT_TX_Pin GPIO_PIN_9
#define BT_TX_GPIO_Port GPIOA
#define BT_RX_Pin GPIO_PIN_10
#define BT_RX_GPIO_Port GPIOA
#define StartADC_Pin GPIO_PIN_11
#define StartADC_GPIO_Port GPIOA
#define CS_Pin GPIO_PIN_12
#define CS_GPIO_Port GPIOA
#define BT_Status_Pin GPIO_PIN_15
#define BT_Status_GPIO_Port GPIOA
#define LED_Pin GPIO_PIN_3
#define LED_GPIO_Port GPIOB
#define SC_Pin GPIO_PIN_4
#define SC_GPIO_Port GPIOB

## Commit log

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2021-02-09 new file: FreeCAD/sc-box-5.FCStd new file: FreeCAD/sc-box-5.stl new file: FreeCAD/sc-cover-5.FCStd new file: FreeCAD/sc-cover-5.stl
    [sc-box-5.FCStd, sc-box-5.stl, sc-cover-5.FCStd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]
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2021-02-11 новый файл: SC9-STM32F103C8Tx-v3/README.md новый файл: SC9-STM32F103C8Tx-v3/bom/ibom.html новый файл: SC9-STM32F103C8Tx-v3/cs новый файл: SC9-STM32F103C8Tx-v3/cs-cache.lib новый файл: SC9-STM32F103C8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
    [cs.csv, cs.kicad_pcb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]
2021-02-27 изменено: SC9-STM32F103C8Tx-v3/cs.kicad_pcb изменено: SC9-STM32F103C8Tx-v3/cs.kicad_pcb-bak изменено: SC9-STM32F103C8Tx-v3/cs.net изменено: SC9-STM32F103C8Tx-v3/cs.pdf изменено: SC9-STM32F103C8Tx-v3/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
    [cs.kicad_pcb, cs.sch]
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2021-03-01 new file: SC-STM32L412K8/SC-STM32L412K8-cache.lib new file: SC-STM32L412K8/SC-STM32L412K8.kicad_pcb new file: SC-STM32L412K8/SC-STM32L412K8.kicad_pcb-bak new file: SC-STM32L412K8/SC-STM32L412K8.net n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
    [SC-STM32L412K8.kicad_pcb, SC-STM32L412K8.sch]
2021-03-08 изменено: SC9-STM32F103C8Tx-v2/cs-cache.lib изменено: SC9-STM32F103C8Tx-v2/cs.sch изменено: SC9-STM32F103C8Tx-v2/cs.sch-bak изменено: STM32Code/.cproject изменено: STM32Code/.settings/language.settin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
    [cs.sch]
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2021-03-12 modified: SC-STM32L412K8/SC-STM32L412K8-cache.lib modified: SC-STM32L412K8/SC-STM32L412K8.kicad_pcb modified: SC-STM32L412K8/SC-STM32L412K8.kicad_pcb-bak modified: SC-STM32L412K8/SC-STM32L412K8.net m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
    [SC-STM32L412K8.kicad_pcb, SC-STM32L412K8.sch]
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2021-03-17 modified: SC-STM32L412K8/SC-STM32L412K8.kicad_pcb modified: SC-STM32L412K8/SC-STM32L412K8.kicad_pcb-bak modified: SC-STM32L412K8/SC-STM32L412K8.net modified: SC-STM32L412K8/SC-STM32L412K8.sch modifie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
    [SC-STM32L412K8.kicad_pcb, SC-STM32L412K8.sch]
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2021-03-19 изменено: SC-STM32L412K8/SC-STM32L412K8-cache.lib изменено: SC-STM32L412K8/SC-STM32L412K8.kicad_pcb изменено: SC-STM32L412K8/SC-STM32L412K8.kicad_pcb-bak изменено: SC-STM32L412K8/SC-STM32L412K8.sch и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
    [SC-STM32L412K8.kicad_pcb, SC-STM32L412K8.sch]
2021-03-21 новый файл: SiPM2/SiPM-cache.lib новый файл: SiPM2/SiPM.bak новый файл: SiPM2/SiPM.kicad_pcb новый файл: SiPM2/SiPM.kicad_pcb-bak новый файл: SiPM2/SiPM.net новый файл: SiPM2/SiPM.pro новый файл: SiP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
    [SiPM.kicad_pcb, SiPM.sch]
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2021-03-30 modified: SC-STM32L412K8/SC-STM32L412K8-cache.lib modified: SC-STM32L412K8/SC-STM32L412K8-rescue.lib modified: SC-STM32L412K8/SC-STM32L412K8.sch modified: SC-STM32L412K8/SC-STM32L412K8.sch-bak modifi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
    [SC-STM32L412K8.sch]
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2021-04-10 изменено: SC-STM32L412K8/SC-STM32L412K8.kicad_pcb изменено: SC-STM32L412K8/SC-STM32L412K8.kicad_pcb-bak изменено: SC-STM32L412K8/SC-STM32L412K8.net изменено: SC-STM32L412K8/SC-STM32L412K8.sch изменен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
    [SC-STM32L412K8.kicad_pcb, SC-STM32L412K8.sch]
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2021-04-18 новый файл: SC-STM32L412K8-light/SC-STM32L412K8-cache.lib новый файл: SC-STM32L412K8-light/SC-STM32L412K8-rescue.bck новый файл: SC-STM32L412K8-light/SC-STM32L412K8-rescue.dcm новый файл: SC-STM32L41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
    [SC-STM32L412K8.kicad_pcb, SC-STM32L412K8.sch]
2021-04-18 изменено: SC-STM32L412K8-light/SC-STM32L412K8-cache.lib изменено: SC-STM32L412K8-light/SC-STM32L412K8.kicad_pcb изменено: SC-STM32L412K8-light/SC-STM32L412K8.kicad_pcb-bak изменено: SC-STM32L412K8-li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
    [SC-STM32L412K8.kicad_pcb, SC-STM32L412K8.sch]
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2021-04-19 modified: SC-STM32L412K8-light/SC-STM32L412K8.kicad_pcb modified: SC-STM32L412K8-light/SC-STM32L412K8.kicad_pcb-bak modified: SC-STM32L412K8-light/SC-STM32L412K8.net modified: SC-STM32L412K8-light/SC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
    [SC-STM32L412K8.kicad_pcb, SC-STM32L412K8.sch]
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2021-05-06 изменено: SC-STM32L412K8-light/SC-STM32L412K8.kicad_pcb изменено: SC-STM32L412K8-light/SC-STM32L412K8.kicad_pcb-bak изменено: SC-STM32L412K8-light/SC-STM32L412K8.net изменено: SC-STM32L412K8-light/SC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
    [SC-STM32L412K8.kicad_pcb, SC-STM32L412K8.sch]
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2021-05-13 modified: FreeCAD/sc-box-7.FCStd modified: FreeCAD/sc-box-7.stl modified: FreeCAD/sc-cover-7.FCStd modified: FreeCAD/sc-cover-7.FCStd1 modified: FreeCAD/sc-cover-7.stl modified: SC-STM32L412K8-light/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
    [SC-STM32L412K8.kicad_pcb, SC-STM32L412K8.sch, sc-box-7.FCStd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]
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2021-05-30 изменено: AndroidDoZer/app/src/main/java/ru/starline/dozer/FullscreenActivity2.java изменено: AndroidDoZer/app/src/main/res/layout/activity_fullscreen2.xml изменено: SC-STM32L412K8-light/SC-STM32L412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
    [SC-STM32L412K8.kicad_pcb, SC-STM32L412K8.sch]
2021-05-31 modified: AndroidDoZer/app/release/app-release.apk modified: AndroidDoZer/app/src/main/java/ru/starline/dozer/FullscreenActivity.java modified: SC-STM32L412K8-light/SC-STM32L412K8-cache.lib modified: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
    [SC-STM32L412K8.sch]
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2021-06-08 renamed: AndroidDoZer/.gitignore -> Android/AndroidDoZer/.gitignore renamed: AndroidDoZer/.idea/.gitignore -> Android/AndroidDoZer/.idea/.gitignore renamed: AndroidDoZer/.idea/.name -> Android/Androi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
    [SC-STM32L412K8.kicad_pcb, SC-STM32L412K8.sch, SiPM.kicad_pcb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]
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

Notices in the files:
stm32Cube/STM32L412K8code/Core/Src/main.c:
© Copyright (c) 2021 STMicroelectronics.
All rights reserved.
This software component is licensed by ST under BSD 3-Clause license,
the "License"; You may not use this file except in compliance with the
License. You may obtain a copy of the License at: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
